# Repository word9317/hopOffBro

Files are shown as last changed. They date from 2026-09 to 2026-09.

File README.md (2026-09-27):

# Hop Off Bro
An alarm clock built for standing desk workers, telling you to switch from sitting to standing or to just hop off!

## Features:
 - 3 Cherry MX switches for input
 - 2.25 in TFT screen
 - LEDs because who doesnt want RGB!
 - Firmware made using PlatformIO for modularity

## Gallery:
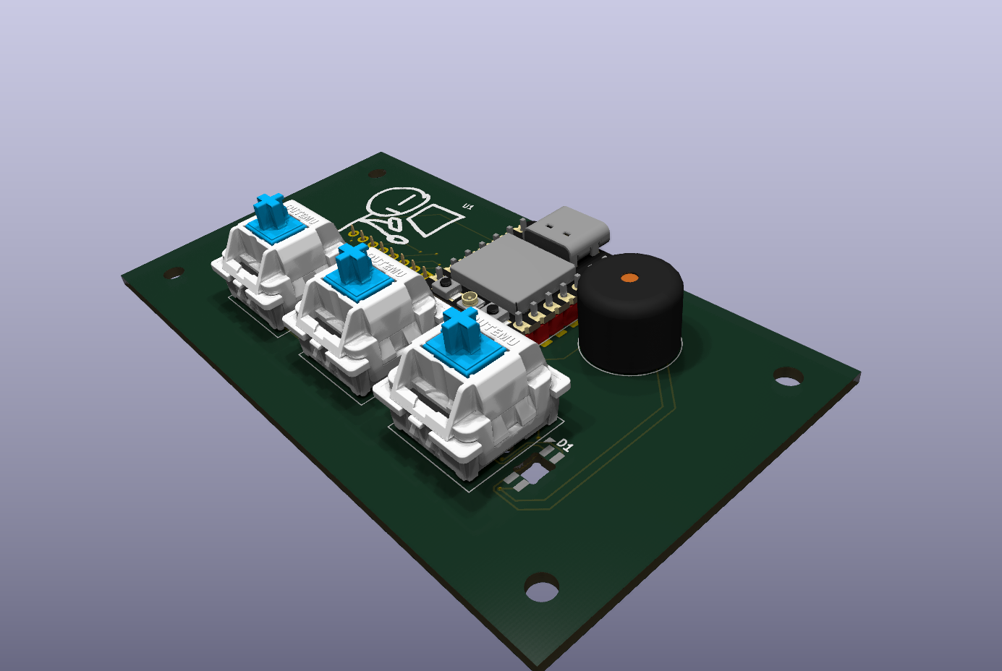
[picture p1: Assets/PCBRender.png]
PCB render

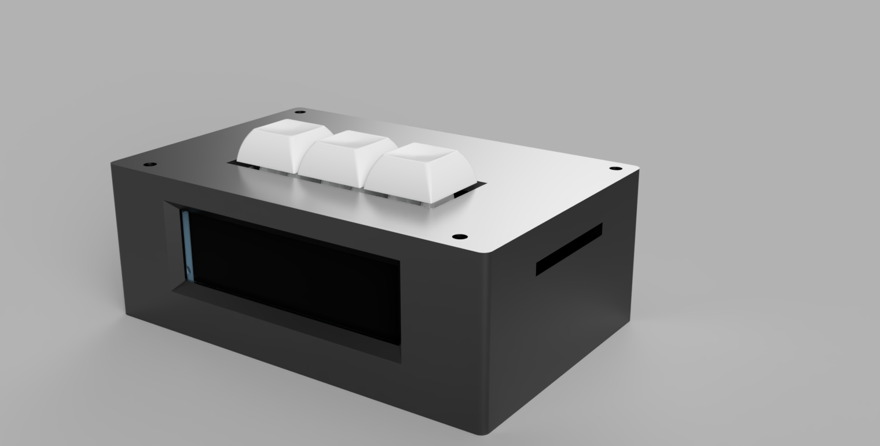
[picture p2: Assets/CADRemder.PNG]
CAD render

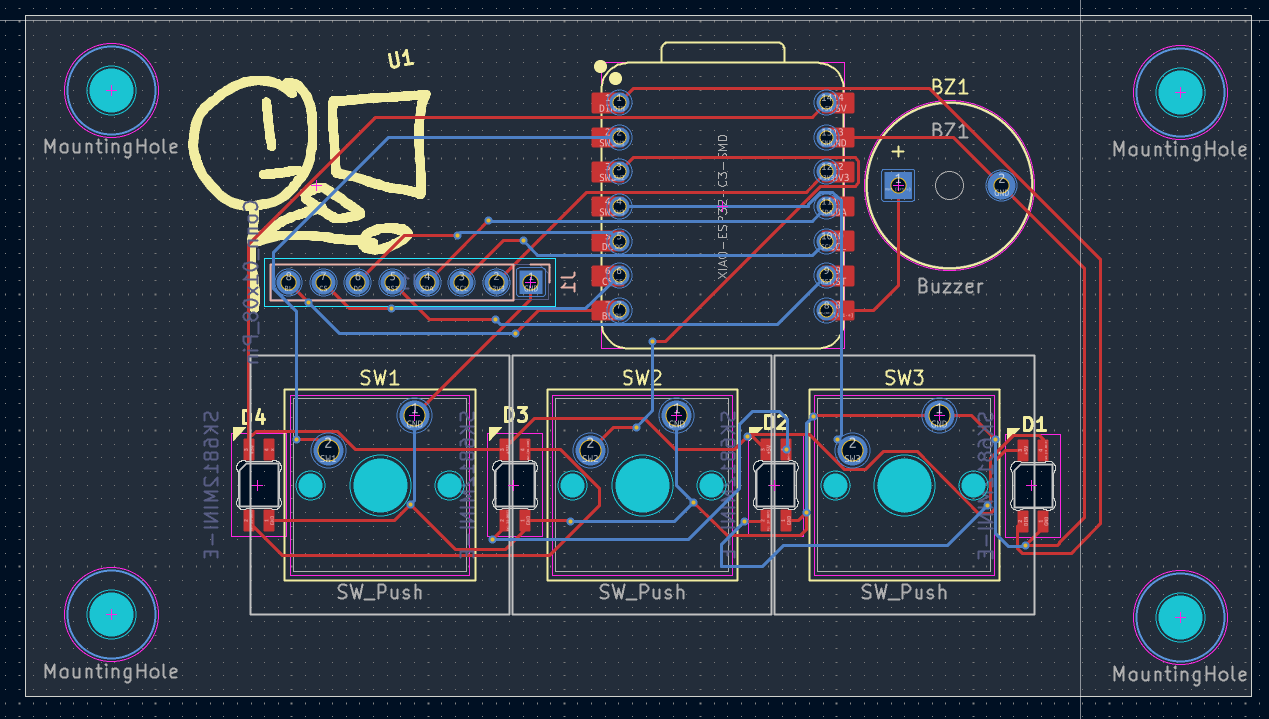
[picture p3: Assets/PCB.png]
PCB

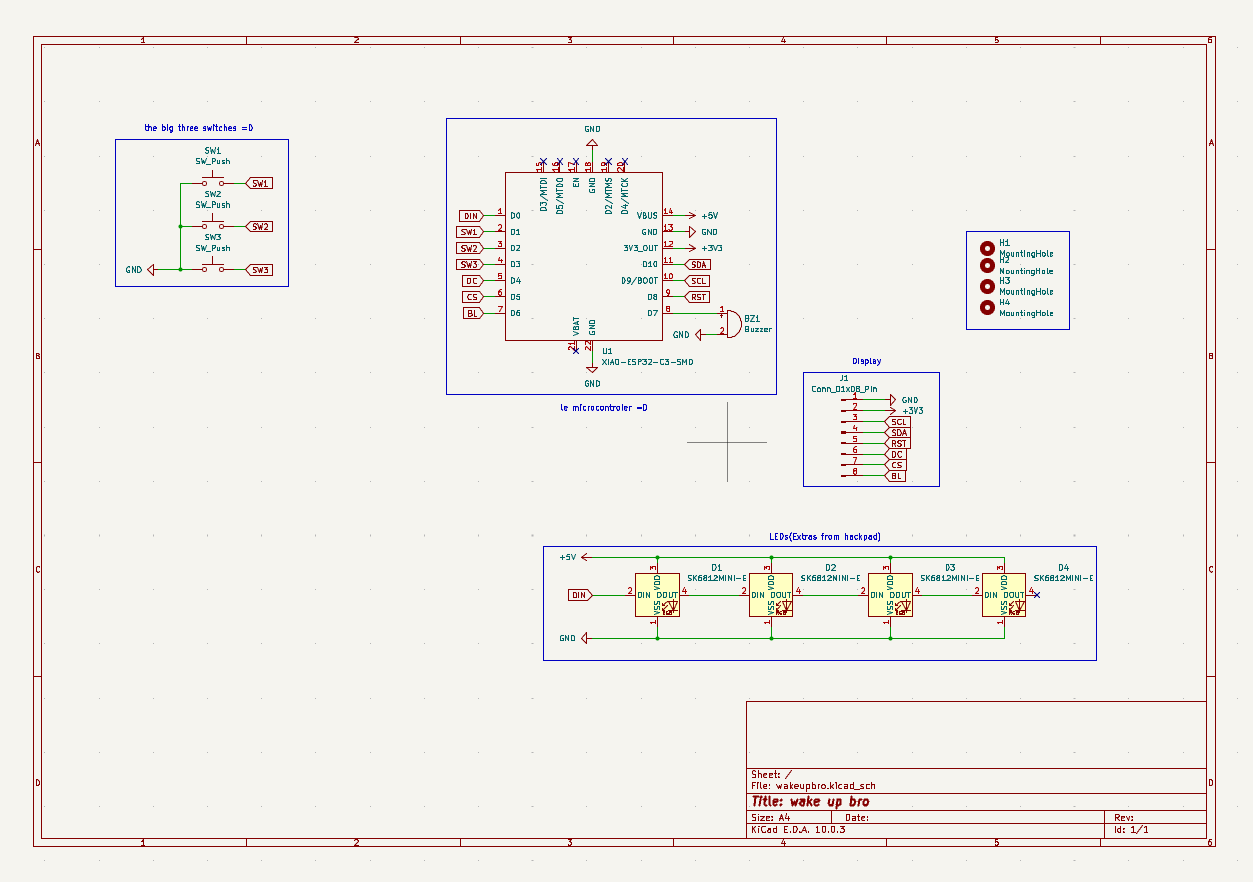
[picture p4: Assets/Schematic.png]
schematic


## BOM:
- 1x Seeed XIAO ESP32C3
- 3x MX-Style Keyboard switches
- 3x White DSA keycaps
- 4x SK6812 LEDs
- 2.54 mm 8 male pin header
- 8x 20cm Female-Female Jumper wires
- 8x M3x5x4 Heatset Inserts
- 4x M3x8mm Screws
- 4x M3x16mm Screws
- 1x 3.3V Piezo Buzzer

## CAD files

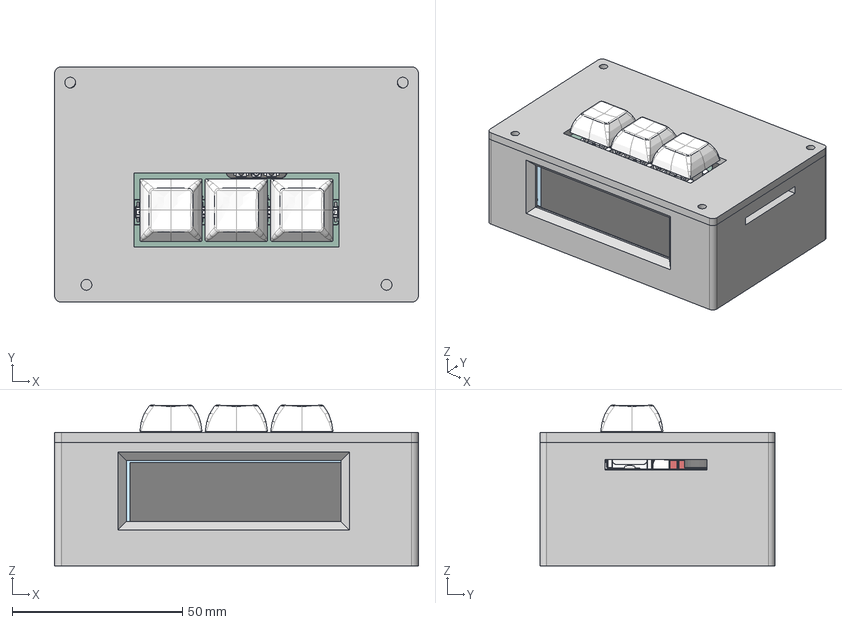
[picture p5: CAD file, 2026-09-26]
CAD/CAD.step
107.0 x 69.2 x 47.2 mm
Pin1 x 4
Pin2 x 4
Pin3 x 4
Pin4 x 4
Header1 x 14
pin x 14
BOSS-EXTRUDE14_8_
BOSS-EXTRUDE7_4_
BOSS-EXTRUDE7_3_
BOSS-EXTRUDE14_4_
BOSS-EXTRUDE14_2_
BOSS-EXTRUDE14_11_
BOSS-EXTRUDE7_7_
BOSS-EXTRUDE14_9_
BOSS-EXTRUDE14_3_
BOSS-EXTRUDE14_7_
MIRROR2
BOSS-EXTRUDE14_5_
BOSS-EXTRUDE14_12_
BOSS-EXTRUDE7_8_
BOSS-EXTRUDE7_1_
BOSS-EXTRUDE14_10_
BOSS-EXTRUDE7_9_
BOSS-EXTRUDE14_6_
BOSS-EXTRUDE14_1_
BOSS-EXTRUDE7_6_
BOSS-EXTRUDE7_2_
CUT-EXTRUDE5
BOSS-EXTRUDE7_5_
U.FL Connector v1
Button (1) x 2
Shield
Buzzer_12x95RM76
PinSocket_1x08_P2.54mm_Vertical_1
wakeupbro_silkscreen
wakeupbro_silkscreen_1
wakeupbro_PCB
BOTT x 3
PIN_1 x 3
SPRIN x 3
CLICK x 3
RET x 3
TOP x 3
Keycap_adjusted x 3
AlarmClockCaseBottom
8 pin header v1_1
8 pin header v1_1_1
8 pin header v1_1_2
8 pin header v1_1_3
8 pin header v1_1_4
8 pin header v1_1_5
8 pin header v1_1_6
8 pin header v1_1_7
8 pin header v1_1_8
Alarm Clock Lid

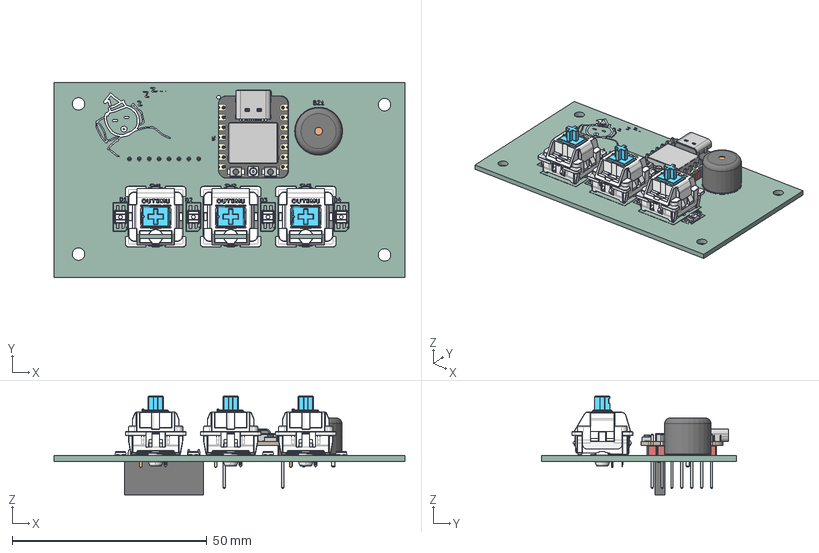
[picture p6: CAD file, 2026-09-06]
PCB/PCBExport.step
90.0 x 50.0 x 25.3 mm
BOTT x 3
PIN x 3
SPRIN x 3
CLICK x 3
RET x 3
TOP x 3
Pin1 x 4
Pin2 x 4
Pin3 x 4
Pin4 x 4
Header1 x 14
pin x 14
BOSS-EXTRUDE14_8_
BOSS-EXTRUDE7_4_
BOSS-EXTRUDE7_3_
BOSS-EXTRUDE14_4_
BOSS-EXTRUDE14_2_
BOSS-EXTRUDE14_11_
BOSS-EXTRUDE7_7_
BOSS-EXTRUDE14_9_
BOSS-EXTRUDE14_3_
BOSS-EXTRUDE14_7_
MIRROR2
BOSS-EXTRUDE14_5_
BOSS-EXTRUDE14_12_
BOSS-EXTRUDE7_8_
BOSS-EXTRUDE7_1_
BOSS-EXTRUDE14_10_
BOSS-EXTRUDE7_9_
BOSS-EXTRUDE14_6_
BOSS-EXTRUDE14_1_
BOSS-EXTRUDE7_6_
BOSS-EXTRUDE7_2_
CUT-EXTRUDE5
BOSS-EXTRUDE7_5_
U.FL Connector v1
Button (1) x 2
Shield
Buzzer_12x95RM76
PinSocket_1x08_P2.54mm_Vertical
wakeupbro_silkscreen x 2
wakeupbro_PCB

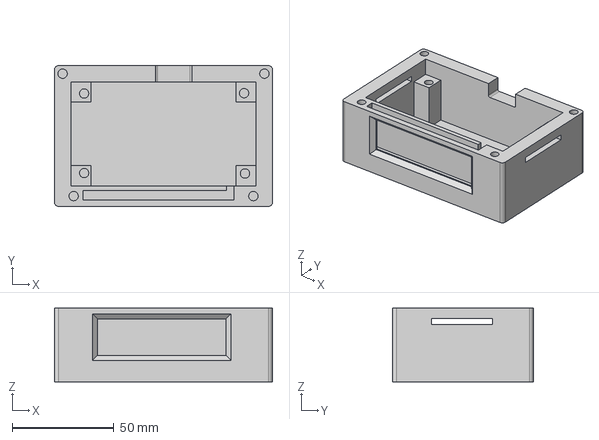
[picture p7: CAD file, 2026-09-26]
Production/BOTTOM.step
107.0 x 69.2 x 36.2 mm

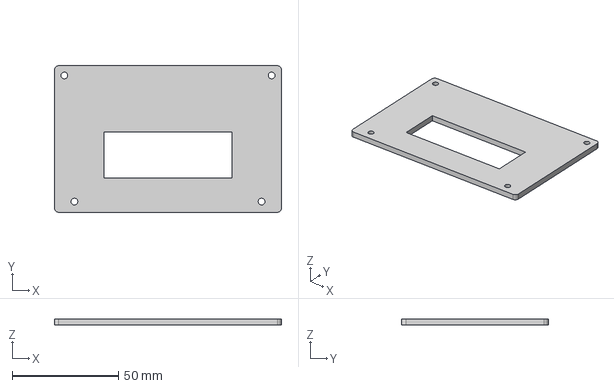
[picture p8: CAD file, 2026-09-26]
Production/TOP.step
107.0 x 69.2 x 3.00 mm

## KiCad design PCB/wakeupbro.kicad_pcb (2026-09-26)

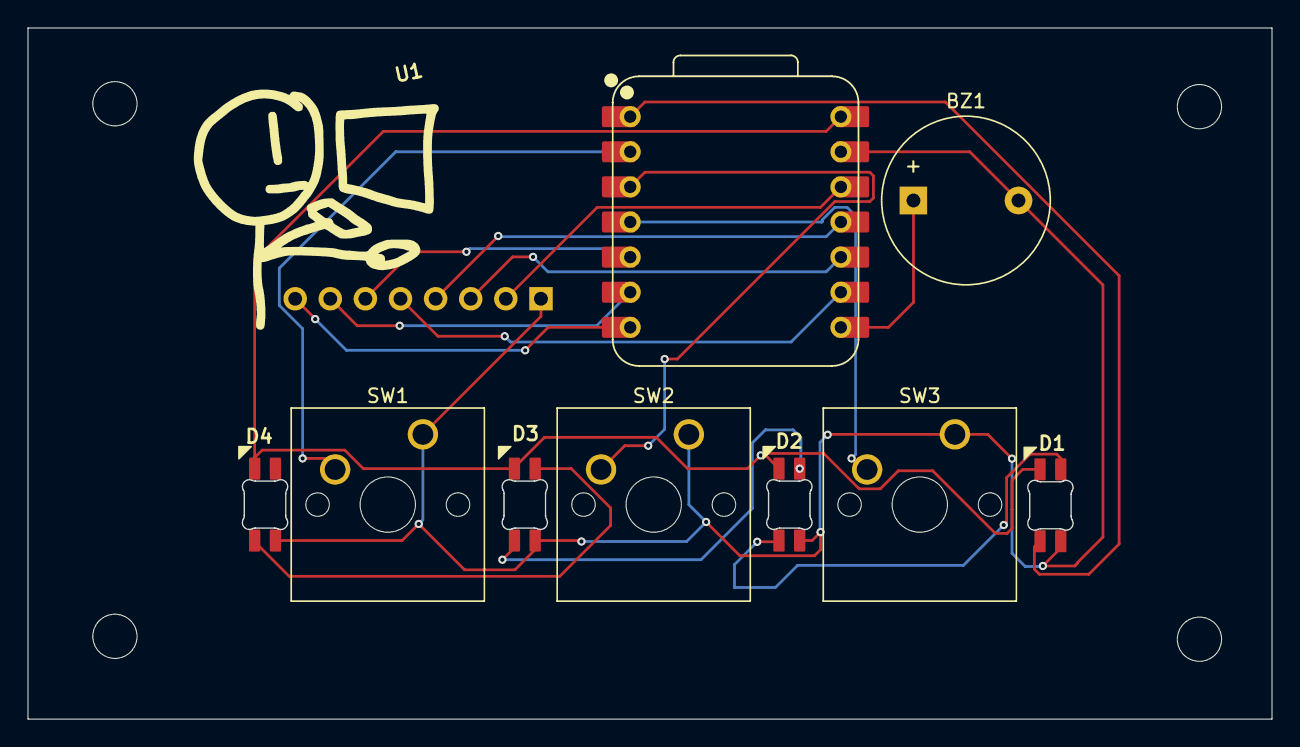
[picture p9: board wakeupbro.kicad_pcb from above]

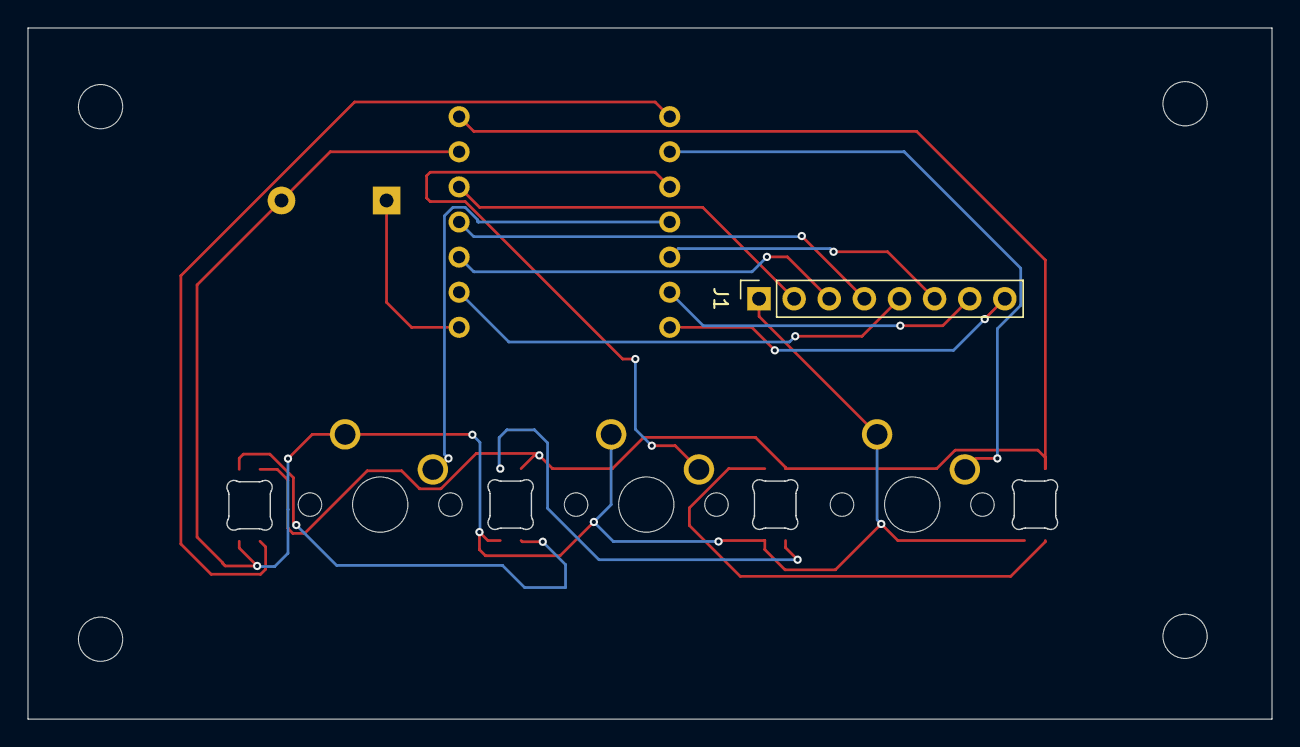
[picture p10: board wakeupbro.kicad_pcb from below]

Board: 2 copper layers, 90.0 x 50.0 mm, 14 parts (5 on the bottom side), 17 nets.

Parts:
BZ1: Buzzer; Buzzer_12x9.5RM7.6
D1, D2, D3, D4: SK6812MINI-E; SK6812MINI-E_fixed
H1, H2, H3, H4: MountingHole; MountingHole_3.2mm_M3
J1: Conn_01x08_Pin; PinSocket_1x08_P2.54mm_Vertical
SW1, SW2, SW3: SW_Push; SW_Cherry_MX_1.00u_PCB
U1: XIAO-ESP32-C3-SMD; XIAO-ESP32-C3-DIP

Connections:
+3V3: J1.2, U1.12 (3V3_OUT)
+5V: D1.3 (VDD), D2.3 (VDD), D3.3 (VDD), D4.3 (VDD), U1.14 (VBUS)
BL: J1.8, U1.7 (D6)
CS: J1.7, U1.6 (D5)
DC: J1.6, U1.5 (D4)
DIN: D1.2 (DIN), U1.1 (D0)
GND: BZ1.2 (-), D1.1 (VSS), D2.1 (VSS), D3.1 (VSS), D4.1 (VSS), J1.1, SW1.1, SW2.1, SW3.1, U1.13 (GND)
unnamed: BZ1.1 (+), U1.8 (D7)
unnamed: D1.4 (DOUT), D2.2 (DIN)
unnamed: D2.4 (DOUT), D3.2 (DIN)
unnamed: D3.4 (DOUT), D4.2 (DIN)
RST: J1.5, U1.9 (D8)
SCL: J1.3, U1.10 (D9/BOOT)
SDA: J1.4, U1.11 (D10)
SW1: SW1.2, U1.2 (D1)
SW2: SW2.2, U1.3 (D2)
SW3: SW3.2, U1.4 (D3)

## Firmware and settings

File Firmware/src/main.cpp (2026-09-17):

#include <Arduino.h>
#include <screenController.h> //custom screen management script
#include <ledController.h> //custom led controller
#include <dateAndTime.h> // date and time via wifi script


// pin declarations
const int swLeft = D1;
const int swMid = D2;
const int swRight = D3;

const int buzzerPin = D7;

// time and resyncing stuff
unsigned long lastSyncMillis = 0;
const unsigned long syncInterval = 60UL * 60 * 1000; // resync every hour


// enums are halla tuff, and im gonan use one for clocks state:
enum clockState { 
  clockIdle,
  timerRunning,
  timerFinished
};

// timer variable declarations
unsigned long timerStartMillis = 0;
unsigned long timerDurationMillis = 0;
uint8_t timerTargetR, timerTargetG, timerTargetB; // color the leds as time gets closer.
bool timerDoneScreenDrawn = false;
unsigned long lastFlashMillis = 0;
bool flashOn = false;
const unsigned long flashInterval = 400; // ms

// button edge detection
bool wasSwLeftPressed = false;
bool wasSwMidPressed = false;
bool wasSwRightPressed = false;

clockState currentState = clockIdle;

String lastTimeShown = "";
String lastDateShown = "";

//helper function for handling button presses isntead of digital reading everywherr.
bool buttonPressed(int pin, bool &wasPressed) {
  bool isPressed = digitalRead(pin) == HIGH;
  bool triggered = isPressed && !wasPressed;
  wasPressed = isPressed;
  return triggered;
}

void showIdleScreen() {
  String timeStr = getTimeString();
  String dateStr = getDateString();

  if (timeStr != lastTimeShown) {
    setScreenText(timeStr, 4, 0, 20);     // left display the time, large n shii
    lastTimeShown = timeStr;
  }

  if (dateStr != lastDateShown) {
    setScreenText(dateStr, 2, 170, 30);   // show the date on the right, js a little smaller
    lastDateShown = dateStr;
  }
}

// timer function
void startTimer(unsigned long minutes, uint8_t r, uint8_t g, uint8_t b) {
  timerDurationMillis = minutes * 60UL * 1000UL;
  timerStartMillis = millis();
  timerTargetR = r;
  timerTargetG = g;
  timerTargetB = b;
  timerDoneScreenDrawn = false;
  lastTimeShown = ""; // resets screen so it is redrawn
  currentState = timerRunning;
}

void showTimerRunning(){
  unsigned long elapsed = millis() - timerStartMillis;

  if(elapsed >= timerDurationMillis){
    //check if time has elapsed, clear leds then
    currentState = timerFinished;
    clearLeds();
    return;
  }
  
  //interpolate color based on how much time is left.
  float progress = (float)elapsed / (float)timerDurationMillis; // used for interpolating color
  uint8_t r = 255 + (int)((timerTargetR - 255) * progress);
  uint8_t g = 255 + (int)((timerTargetG - 255) * progress);
  uint8_t b = 255 + (int)((timerTargetB - 255) * progress);

  setAllLeds(r, g, b);
  showleds();

  unsigned long remainingSec = (timerDurationMillis - elapsed) / 1000;
  int mm = remainingSec / 60;
  int ss = remainingSec % 60;
  char buf[6];
  snprintf(buf, sizeof(buf), "%02d:%02d", mm, ss);
  String remainingStr = String(buf);

  if (remainingStr != lastTimeShown) {
    setScreenText(remainingStr, 4, 0, 20);
    lastTimeShown = remainingStr;
  }
}

void showTimerDone(){
  if(!timerDoneScreenDrawn){
    clearScreen();
    setScreenText("hop off bro!", 3, 20, 100);
    timerDoneScreenDrawn = true;
  }

  //flasing lights
  unsigned long now = millis();
  if(now-lastFlashMillis >= flashInterval){
    lastFlashMillis = now;
    flashOn = !flashOn;
    
    if(flashOn){
      setAllLeds(0, 255, 0);
      showleds();
      screenBacklightOn();
      tone(buzzerPin, 1000);
    } else {
      clearLeds();
      screenBacklightOff();
      noTone(buzzerPin);
    }
  }
}

void setup() {
  // set up switches
  pinMode(swLeft, INPUT);
  pinMode(swMid, INPUT);
  pinMode(swRight, INPUT);

  //setup buzzer thingy
  pinMode(buzzerPin, OUTPUT);

  // initialize subsystems(i feel so fancy writing that)
  setupLeds();
  setupTFT();
  connectToWiFi();
  syncNTPTime();
  disconnectWiFi();
  lastSyncMillis = millis();
}

void loop() {
  // hourly WiFi resync check
  if (millis() - lastSyncMillis >= syncInterval) {
    connectToWiFi();
    syncNTPTime();
    disconnectWiFi();
    lastSyncMillis = millis();
  }

  bool leftPressed = buttonPressed(swLeft, wasSwLeftPressed);
  bool midPressed = buttonPressed(swMid, wasSwMidPressed);
  bool rightPressed = buttonPressed(swRight, wasSwRightPressed);

  switch (currentState) {
    case clockIdle:
      if(leftPressed){
        startTimer(20, 255, 0, 0);
      } else if (rightPressed){
        startTimer(30, 0, 0, 255);
      }
      showIdleScreen();
      break;
    
    case timerRunning:
      if(midPressed){
        clearLeds();  
        currentState = clockIdle;
      }
      showTimerRunning();
      break;
    
    case timerFinished:
      showTimerDone();
      if(leftPressed || midPressed || rightPressed) {
        noTone(buzzerPin);
        clearLeds();
        screenBacklightOn();
        timerDoneScreenDrawn = false;
        currentState = clockIdle;
      }
      break;
  }
}

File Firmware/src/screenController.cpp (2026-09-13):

#include <Arduino.h>
#include <Adafruit_GFX.h>    // graphics library
#include <Adafruit_ST7789.h> // driver for the ST7789 screen
#include <SPI.h>

// the screens pins(hopefully right)
const int TFT_SCLK = D9;  // labeled SCL on the screen
const int TFT_MOSI = D10; // labeled SDA on the screen
const int TFT_RST  = D8;
const int TFT_DC   = D4;
const int TFT_CS   = D5;
const int TFT_BL   = D6;

bool screenInitialized = false;
// create a class for the screen
class MyST7789 : public Adafruit_ST7789
{
public:
    MyST7789(int8_t cs, int8_t dc, int8_t mosi, int8_t sclk, int8_t rst)
        : Adafruit_ST7789(cs, dc, mosi, sclk, rst) {}
    void setOffsets(uint8_t col, uint8_t row)
    {
        _colstart = _colstart2 = col;
        _rowstart = _rowstart2 = row;
    }
};
// give the tft screen its pin values
MyST7789 tft(TFT_CS, TFT_DC, TFT_MOSI, TFT_SCLK, TFT_RST);

// set text on the tft display
void setScreenText(String message, uint8_t textSize, int cursorX, int cursorY )
{
    if (screenInitialized)
    {
        tft.setTextSize(textSize);    // set text size
        tft.setTextColor(ST77XX_WHITE);  // set the color
        tft.setCursor(cursorX, cursorY);          // cursor reset
        tft.print(message);         // set message on clock to the message inputed into function
    }
}

//clear le screen
void clearScreen(){
    if(screenInitialized){
        tft.fillScreen(ST77XX_BLACK); //clear the screen
    }
}

//functions for backlight
void screenBacklightOn(){
    digitalWrite(TFT_BL, LOW);
}
void screenBacklightOff(){
    digitalWrite(TFT_BL, HIGH);
}

// function to set up the TFT display, will run during setup of main.cpp
void setupTFT()
{
    pinMode(TFT_BL, OUTPUT);   // Set the backlight pin mode, or just wire it to 3.3V
    digitalWrite(TFT_BL, LOW); // Turns the backlight ON, for some reason this screen is active Low, so setting it to LOW is really HIGH

    // ok now we init le screen
    tft.init(76, 284);
    tft.setOffsets(82, 18);
    tft.invertDisplay(false);
    tft.setRotation(1); // might have to change to 3 if display is flipped
    tft.fillScreen(ST77XX_BLACK);
    tft.setTextColor(ST77XX_WHITE);
    tft.setTextSize(6);
    tft.setCursor(0, 0);
    screenInitialized = true;
}

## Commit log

2026-08-30 Initial update with pcb. PCB is currently just a schematic, everything is hooked up, but footprints are still remaining
    [wakeupbro.kicad_pcb, wakeupbro.kicad_sch]
2026-08-30 Organized schematic a bit and just yea idk.
    [wakeupbro.kicad_sch]
2026-08-31 Routed PCB, silkscreen art soon...
    [wakeupbro.kicad_pcb, wakeupbro.kicad_sch]
2026-09-06 Add finished PCB and exported step file of the PCB
    [PCBExport.step, wakeupbro.kicad_pcb]
2026-09-12 Update PCB files. Going to start workig on firmware
    [wakeupbro.kicad_pcb, wakeupbro.kicad_sch]
2026-09-13 forgot to remove resetting screen
    [screenController.cpp]
2026-09-13 LED controller for SK6812
2026-09-17 Finished firmware, use left switch for 20 min timer, right for 30 min, middle for canceling. leds dynamically change color, at the end buzzer buzzes, leds and backlight flash
    [main.cpp]
2026-09-26 add final files
    [BOTTOM.step, CAD.step, TOP.step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]
2026-09-27 forgot schematic picture
